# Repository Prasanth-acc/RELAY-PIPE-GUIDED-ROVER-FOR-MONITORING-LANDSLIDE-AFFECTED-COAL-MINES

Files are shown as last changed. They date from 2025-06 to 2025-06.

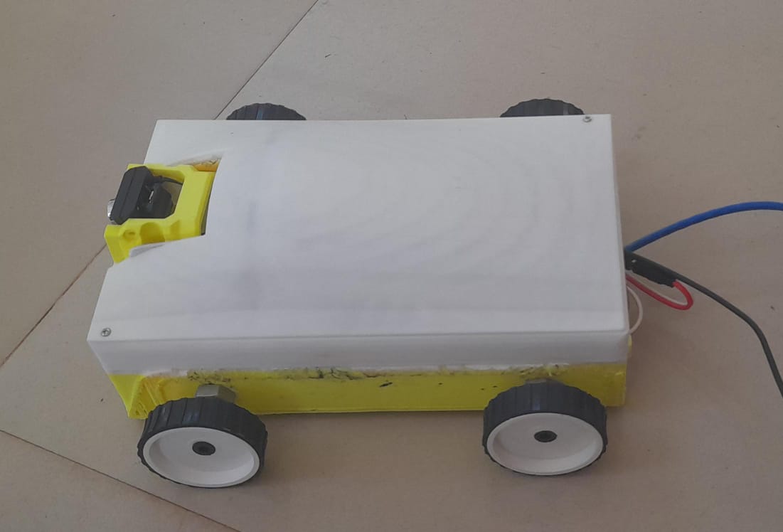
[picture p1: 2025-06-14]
Images/rover final.jpg

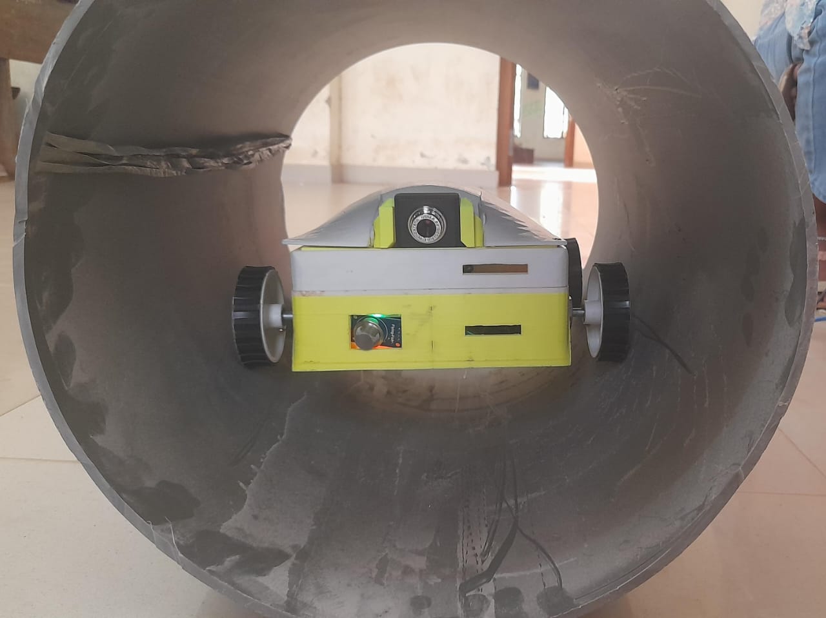
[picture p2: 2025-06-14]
Images/rover inside pipe.jpg

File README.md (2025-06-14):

# RELAY-PIPE-GUIDED-ROVER-FOR-MONITORING-LANDSLIDE-AFFECTED-COAL-MINES
This project develops a compact, remotely controlled rover designed for monitoring underground coal mines. Using custom CAD-designed parts, the rover navigates tight tunnels and gathers real-time data to assess mine safety. Communication with the base station is done via a wired RJ45 Ethernet connection to ensure reliable data transfer in challenging underground environments.

The rover is equipped with sensors and a camera system that allow operators to control its movement and view live feedback from the mine. This setup provides a safer way to monitor hazardous conditions and helps plan rescue operations by delivering crucial information without exposing humans to risk.
# ABSTRACT
In the wake of coal mine collapses, where workers often find themselves trapped and
 isolated, the urgency for rapid and effective rescue operations is paramount. This
 project aims to address such critical situations by designing and developing a state
of-the-art rover capable of navigating through a strategically drilled pipe to the far side
 of a collapsed mine. The primary objective is to equip rescue teams with real-time
 data and communication capabilities, significantly enhancing the efficiency and safety
 of underground rescue missions.
 
 The rover is engineered to traverse through a narrow pipe drilled through the soil,
 reaching the trapped zone with precision. It is equipped with high-resolution cameras
 capable of capturing detailed images even in low-light conditions, along with advanced
 environmental sensors that measure critical parameters such as gas levels, temperature,
 and humidity. Central to the rover's functionality is the BeagleY-AI board, which serves as the onboard processing unit.These sensors and cameras are vital for assessing the conditions within
 the collapsed mine and detecting potential hazards that could endanger the lives of both
 the trapped workers and the rescue team.
 
 Central to the rover’s functionality is its onboard processing unit, which integrates
 and analyses captured data in real-time. This processing capability ensures that
 only relevant and high-priority information is managed efficiently while transmitting
 everything directly to the base station via a wired connection with real-time, instan
taneous transmission. Unlike traditional wireless communication, which suffers from
 signal interference and delays in underground environments, this wired communication
 system guarantees uninterrupted and ultra-fast data transfer of video, sensor data, and
 audio.
 
 The base station is equipped with a dedicated Graphical User Interface (GUI)
 that enables rescue teams to view live footage, monitor sensor readings, and control
the rover remotely in real time. The instantaneous transmission allows operators
 to make swift and informed decisions. Moreover, the rover facilitates direct two
way communication with trapped workers, allowing rescue teams to provide real-time
 instructions and reassurance while receiving critical updates from the workers location.
 This feature is crucial in maintaining morale and gathering first-hand information about
 the situation.
 
 By integrating the BeagleY-AI board with environmental sensing, and a robust, real-time
 wired communication system, this project aims to offer a comprehensive solution
 for underground rescue operations. The developed rover will provide rescuers
 with invaluable insights, enabling them to make swift, informed decisions, thereby
 increasing the likelihood of a successful rescue. This innovative approach not only
 enhances the effectiveness of emergency response efforts in coal mine disasters but
 also sets a new standard for safety in hazardous underground environments.

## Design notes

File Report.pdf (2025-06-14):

# Contents

Abstract | i
Acknowledgement | iii
List of Figures | vii
1 Introduction | 1
2 Motivation | 2
3 Literature Review | 3
4 Methodology | 5

iv

5 Implementation | 12
6 Hardwares and Softwares | 17

v

7 Program | 22
8 | Result | 38
9 Scope for future applications | 41
10 Conclusion | 43
References | 45

vi

# List of Figures

4.1 2D design of rover | | 7
4.2 Model of lower chassis | | 8
4.3 Model of upper chassis | | 8
4.4 Model of rover | | 8
4.5 GUI | | 9
4.6 Simple program in Beagle Y AI board | | 10
5.1 Block diagram | | 12
5.2 Hardware circuit diagram | | 14
6.1 Beagle Y AI board | | 17
6.2 Arducam 1MX477 | | 18
6.3 MQ135-gas sensor | | 18
6.4 DHT11-temperature and humidity sensor | | 19
6.5 Slim Mini Audio Speaker (80 Ohm, 24x40mm) | | 19
6.6 InvenSense ICS43434-microphone | | 20
8.1 Final 3D model of rover | | 38
8.2 Hardware integration | | 39
8.3 GUI at base station | | 39
8.4 rover moving through pipe | | 40
8.5 output from beagle board | | 40

vii

# Chapter 1

# Introduction

The increasing frequency of mining accidents and natural disasters has necessitated

the development of innovative solutions for effective search and rescue operations. In

situations where traditional rescue methods may be hindered by debris or confined

spaces, robotic technologies offer a viable alternative to enhance safety and efficiency.

This project introduces an advanced rover specifically designed to navigate through

strategically drilled pipes, providing access to areas that are otherwise challenging for

human rescuers.

Equipped with high-resolution cameras and sophisticated environmental sensors,

the rover captures real-time images and monitors environmental conditions. Utilizing

the BeagleY-AI board for onboard processing, the rover employs advanced image

processing algorithms to enhance visibility in low-light and dusty environments, which

is critical for assessing the conditions of trapped individuals.

To facilitate effective communication, the rover features a two-way audio system,

allowing trapped individuals to interact directly with rescuers. This interaction not

only provides emotional support but also enables rescuers to gather vital information,

improving the overall effectiveness of the rescue effort.

This project aims to demonstrate the potential of robotics in enhancing the safety

and effectiveness of rescue operations. By integrating real-time video transmission,

environmental sensing, and communication technologies, the rover serves as a vital

resource in improving outcomes in emergency situations, ultimately contributing to

the successful recovery of trapped individuals.

1

# Chapter 2

# Motivation

The motivation behind this project arises from the significant safety challenges and

operational hazards associated with coal mining, particularly in the aftermath of

landslides. Landslides in mining areas can create unstable environments,obstruct

pathways, and release hazardous gases,making it dangerous and often impossible for

personnel to conduct direct inspections. Such conditions call for advanced solutions

that can mitigate risks while ensuring effective monitoring and data collection.

Traditional inspection methods are either labor-intensive or unsuitable for confined

spaces filled with toxic gases, low visibility, and unstable terrain. Robotic systems offer

a promising alternative by enabling remote, real-time assessment without endangering

human lives. By deploying a specialized rover that integrates navigation aids, multi-

sensor capabilities, and reliable communication systems, this project aims to enhance

post-landslide safety protocols.

Moreover, the rising demand for more autonomous and efficient mining solutions

emphasizes the need for innovation in this field. The rover’s ability to navigate through

strategically drilled pipes and perform detailed environmental monitoring could lead to

broader applications in mining, rescue operations, and even other high-risk industries.

The project is, therefore, driven by a commitment to improving mine safety, increasing

efficiency, and minimizing the risks associated with underground inspections.

2

# Chapter 3

# Literature Review

The Role of Robotics in Hazardous Environments[1,3]: Robotics has gained

significant attention for applications in hazardous and inaccessible areas, where human

presence may be unsafe or impractical. Many researchers highlights that autonomous

and semi-autonomous robotic systems have been successfully deployed in high-risk

areas, such as nuclear plants, deep-sea exploration, and disaster-stricken zones. These

robots can perform inspections, monitor environmental conditions, and relay critical

information back to human operators. This capability is particularly important in post-

landslide scenarios within coal mines, where unstable structures and toxic gases create

unsafe conditions for humans. Robotic inspection systems provide a viable solution by

reducing risk while allowing continuous data collection to assess stability and safety.

Guidance and Navigation in Confined Space [4]: Navigation in confined

and debris-filled spaces, such as those found in coal mines, requires specialized

techniques to ensure stability and accuracy, which emphasize the importance of guided

systems—rails, tethers, or relay pipes—that allow robots to move safely through

narrow and hazardous areas. Relay pipes, specifically, provide a path that helps

maintain the stability and orientation of the rover, even in environments with poor

visibility or challenging terrain. This technology has been applied in urban search-and-

rescue missions, showing success in guiding robotic platforms through narrow spaces

while preventing deviations that could lead to navigation errors or loss of control.

Environmental Monitoring and Gas Detection in Mining Applications [2,7,8]:

One of the most critical safety concerns in coal mines is the presence of toxic or explo-

3

sive gases, including methane and carbon monoxide. The mining industry frequently

encounters these gases, especially following landslides, as they can accumulate in

newly created cavities or pockets.Ga s sensors, such as the MQ-series (e.g., MQ-7

for carbon monoxide and MQ-4 for methane), have become standard for real-time

monitoring in underground environments, which shows that these sensors are effective

in identifying dangerous gas concentrations and can be integrated into mobile robotic

systems for continuous monitoring. Additionally, infrared (IR) gas sensors have been

used for detecting methane due to their accuracy and sensitivity. Integrating such

sensors into an inspection rover provides a reliable means of assessing air quality and

warning operators of dangerous levels of toxic gases.

Ethernet Communication in Robotics [9,14,10]: Ethernet technology has be-

come a cornerstone in industrial robotics, providing a standardized, high-bandwidth

medium for data exchange between system components. The adoption of Ethernet-

based protocols, enables seamless integration with existing network infrastructures,

enhancing interoperability and simplifying system architecture. This integration

allows for centralized control and data collection, improving efficiency and reducing

latency in robotic operations.

4

# Chapter 4

# Methodology

## 4.1 System Design and Requirements Analysis:

The development of the rover began with an in-depth analysis of the operational

requirements needed for effective deployment in confined underground environments.

The primary objective was to create a compact yet efficient system capable of

maneuvering through relay pipes drilled in collapsed coal mines. Key considerations

included designing a structure that ensures seamless mobility, integrating a robust

wired communication system for uninterrupted data transmission, and incorporating

environmental sensors for real-time monitoring of hazardous gases, temperature,

and humidity levels. The rover was also required to support real time video

transmission and bidirectional audio communication, enabling real-time interaction

between trapped workers and rescue operators.To enhance usability, a graphical user

interface (GUI) was developed at the base station, providing a centralized platform

for monitoring and controlling the rover. This interface displays the real-time video

feed, environmental sensor readings, and system diagnostics, ensuring operators have

all necessary data at a glance. Additionally, the GUI includes interactive controls,

allowing operators to navigate the rover remotely and make crucial decisions based

on live feedback. These requirements guided the selection of appropriate hardware

components, communication technologies, and software development strategies to

ensure the rover’s reliability in rescue operations.

| 5

## 4.2 Hardware Selection and Integration:

### 4.2.1 Locomotion and Chassis Design:

The chassis design focused on creating a lightweight yet structurally stable frame that

could navigate through confined spaces while withstanding underground conditions.

The rover was designed to move within a relay pipe, requiring a compact and durable

body that would prevent obstruction while maintaining balance. High-torque DC

motors were selected to drive the wheels, ensuring sufficient force for movement while

operating efficiently within the power constraints .

### 4.2.2 Power Supply and Distribution:

The rover is powered by a battery-based power supply, ensuring mobility without

dependence on external power sources. A lithium-polymer (LiPo) battery was selected

for its high energy density, lightweight characteristics, and ability to supply a stable

voltage output. A power management circuit was designed to regulate voltage levels,

preventing over voltage or under voltage conditions that could impact the performance

of motors and sensors. The distribution system was optimized to efficiently supply

power to all components, ensuring prolonged operational capability while maintaining

safety measures such as short-circuit protection and thermal management.

4.2.3 Sensor and Camera Integration;

To enhance situational awareness in the underground environment, the rover was

equipped with environmental monitoring sensors and a high-resolution camera system.

Gas sensors were integrated to detect hazardous gases.Additionally,temperature and

humidity sensors were added to provide real-time environmental data to rescue

operators. A high-resolution camera was mounted on the rover to capture live video

footage, which was transmitted to the base station.

6

### 4.2.4 Wired Communication Implementation:

A critical aspect of the rover’s design was the implementation of wired communication

technology to enable real-time data transmission.This system facilitated real-time con-

trol of the rover, bidirectional audio communication, and live video streaming. Control

signals from the base station were transmitted through the wired network, allowing

precise maneuverability and real-time response from the rover. The wired approach

eliminated concerns regarding wireless signal interference or loss of connectivity in

underground environments.

## 4.3 2D Design and Initial Conceptualization:

Following the component selection, a hand-drawn 2D design was created to visualize

the layout and arrangement of the components within the available space. The

hand-drawn design(Figure 4.1) provided an understanding of the positioning of each

component, ensuring efficient space usage and proper weight distribution for balanced

navigation. This initial conceptualization allowed for quick revisions and adjustments,

ensuring flexibility in the design process and ensured that all components would fit

within the confined space of the pipe, with an emphasis on stability to minimize tipping

risks.

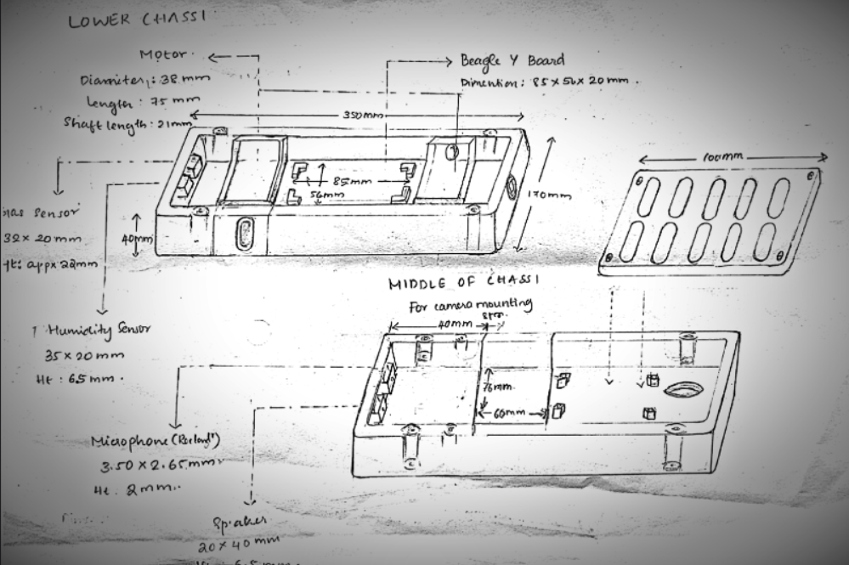
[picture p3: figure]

Figure 4.1: 2D design of rover

7

## 4.4 3D Modeling and Component Design:

After the 2D design, the rover was transitioned into a 3D model using CAD software,

SolidWorks.The 3D modeling phase provided a more detailed visualization of the

rover’s components in three dimensions, ensuring their fit and arrangement as shown

in Figure 4.2 ,Figure 4.3 and Figure 4.4. This step helped to identify potential issues

such as component overlap or misalignment. Adjustments were made to optimize

component sizes and positions to ensure effective navigation within the pipe while

maintaining the rover’s structural integrity and balance. The 3D model allowed for

accurate representation of the rover’s physical design, aiding in the evaluation of space

utilization and structural efficiency.

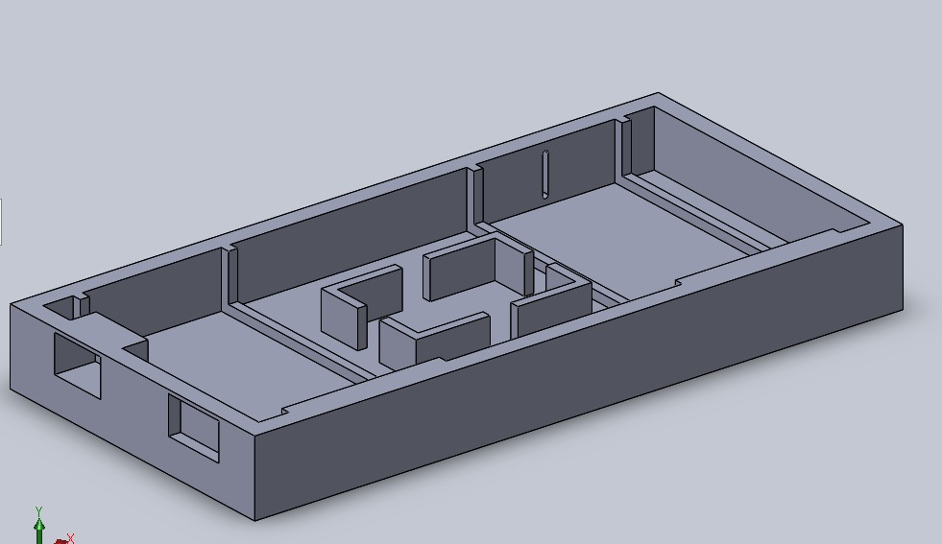
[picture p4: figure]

Figure 4.2: Model of lower chassis

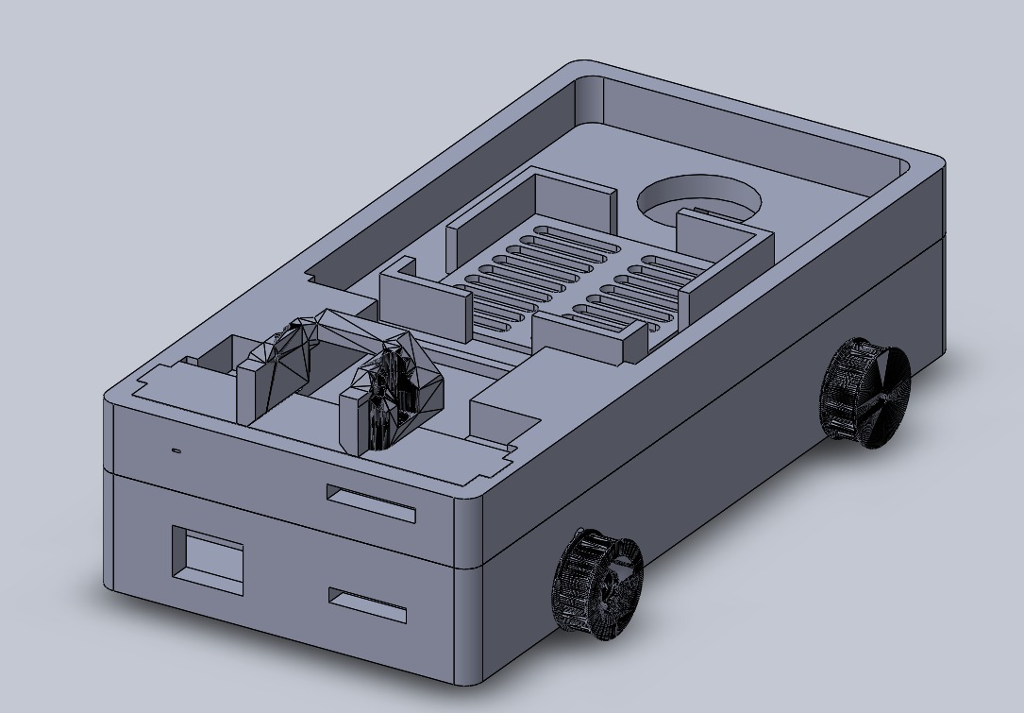
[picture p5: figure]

Figure 4.3: Model of upper chassis

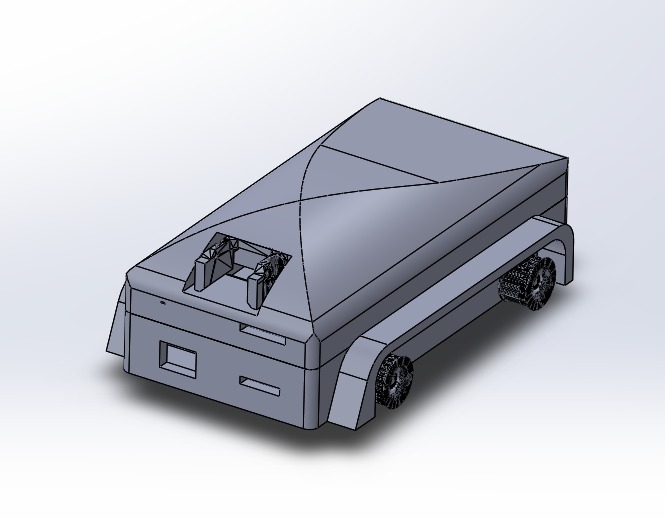
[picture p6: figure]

Figure 4.4: Model of rover

8

## 4.5 Software Development

### 4.5.1 Programming and Implementation:

The software architecture was developed to handle real-time video processing, sensor

data acquisition, and remote control functionalities. Python is used to program

the system, with multi-threading techniques employed to manage simultaneous data

transmission, motor control, and environmental monitoring. The rover’s software was

designed to interface with the base station, where a Graphical User Interface (GUI)

was developed to display live video feeds, sensor readings, and control parameters.

### 4.5.2 Graphical User Interface (GUI) at the Base Station:

A dedicated Graphical User Interface (GUI) was developed at the base station to

facilitate seamless interaction with the rover. The GUI serves as the central control

hub where all data from the rover, including live video feeds, environmental sensor

readings, and system status, are displayed in real-time. The interface allows rescue

operators to monitor underground conditions, analyze images processed by the rover,

and adjust control parameters as needed. Additionally, the GUI (Figure 4.5) provides

interactive controls for operating the rover, such as adjusting its movement and sensor

data.

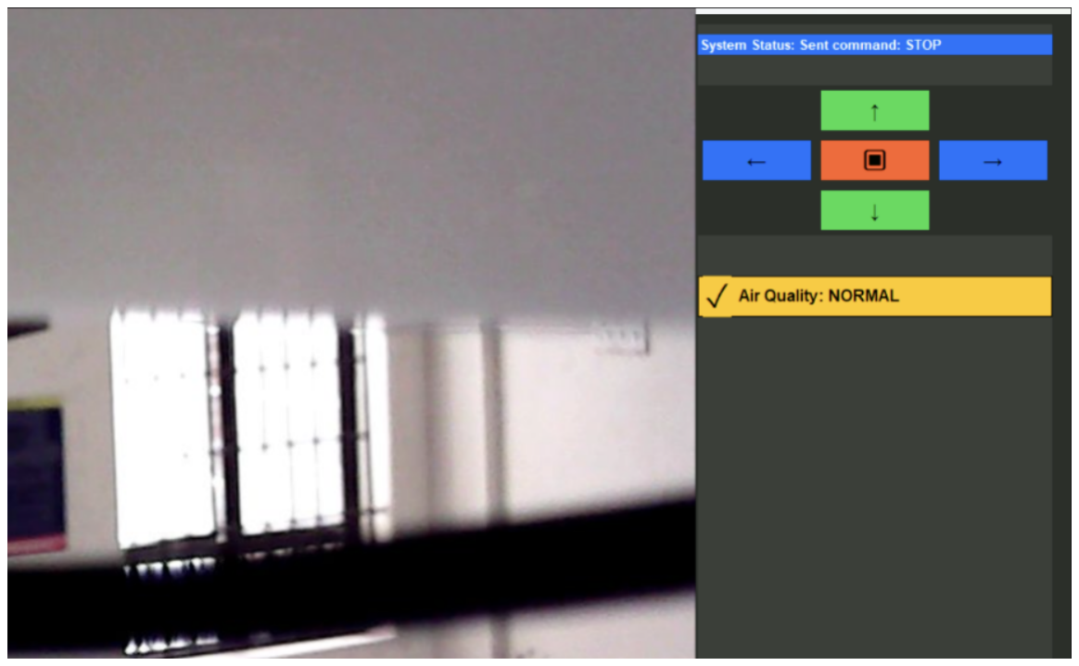
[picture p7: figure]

Figure 4.5: GUI

9

## 4.6 Hardware Testing:

Before full-scale deployment, individual hardware components were tested to ensure

their functionality. The motors, sensors, and communication modules were evaluated

under controlled conditions to verify their responsiveness and reliability. The Beagle

Y AI board was used to execute simple test programs that assessed sensor data

acquisition and motor operation. These preliminary tests confirmed that the rover could

process environmental inputs and execute movement commands accurately. The wired

communication system was tested separately to measure latency,and overall stability in

data transmission. Control signals, bidirectional audio communication, and real-time

video streaming were evaluated under simulated underground conditions. The results

indicated that the system could handle continuous data flow without delays, ensuring

effective remote operation.

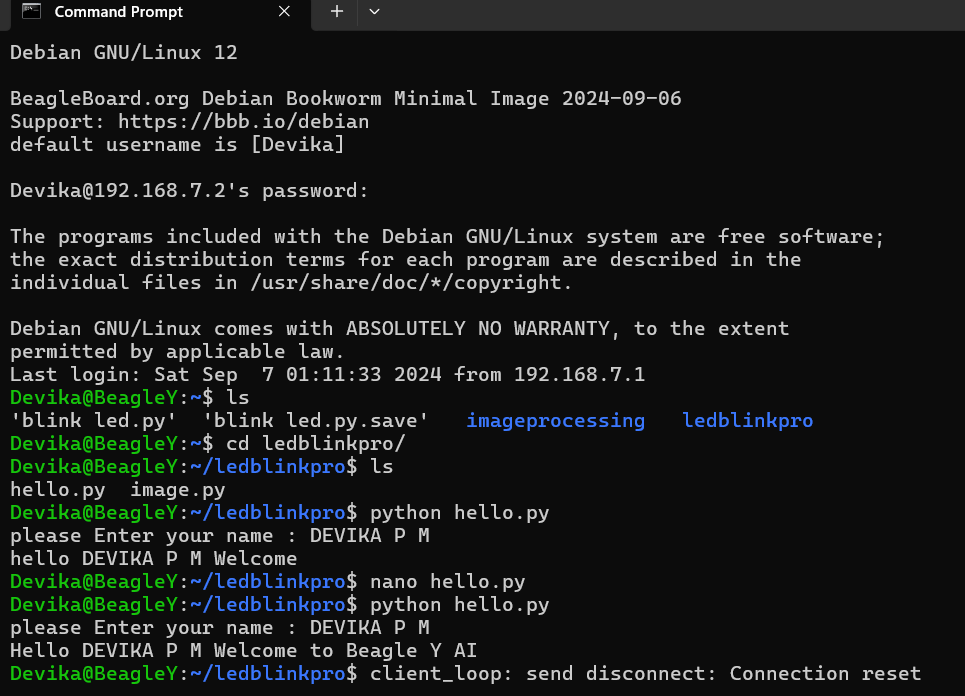
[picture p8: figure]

Figure 4.6: Simple program in Beagle Y AI board

## 4.7 Testing and Performance Evaluation

### 4.7.1 Environmental Sensor Validation:

The accuracy of the environmental sensors was tested in a controlled setup by exposing

them to varying conditions. Gas sensors were calibrated to detect different gases, under

different environmental conditions to ensure precise readings.

10

### 4.7.2 Rover Navigation Testing:

A simulated test environment was created to evaluate the rover’s movement through

a relay pipe. The rover was tested for stability, maneuverability, and response

to control signals. Adjustments were made to improve its movement and ensure

efficient navigation within confined spaces.The rover’s response to control signals was

tested to measure real-time communication effectiveness, ensuring minimal latency in

command execution.

### 4.7.3 Performance Analysis and Optimization

To ensure the rover’s reliability and efficiency, a series of performance tests were

conducted, focusing on communication latency, power efficiency, structural durability,

and environmental adaptability. The rover’s response time to control signals was

analyzed to minimize latency, with software optimizations implemented for real-

time communication. Its maneuverability was tested in confined spaces, leading

to adjustments in motor control algorithms for smoother turns and better path

optimization.

11

# Chapter 5

# Implementation

## 5.1 System Architecture(Conceptual Design)

The block diagram(Figure 5.1) represents the working architecture of the rover system,

which is designed to navigate and communicate through a wired connection

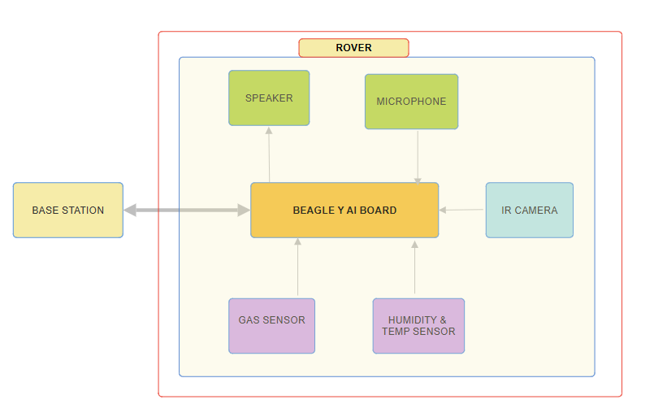
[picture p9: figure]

Figure 5.1: Block diagram

### 5.1.1 BeagleY-AI Board (Central Processing Unit)

The BeagleY-AI board is responsible for processing data, and controlling various

hardware components. It receives input from sensors and the microphone, processes

the data, and sends output commands to the motors, speaker, and base station.The

board also facilitates real-time wired communication with the base station.

12

### 5.1.2 Environmental sensors

Gas Sensor Detects air quality and sends data to the BeagleY-AI board.Humidity

and Temperature Sensor, Measures environmental conditions and provides necessary

information for analysis.

### 5.1.3 Microphone and Speaker

Microphone Captures real-time audio from the rover’s surroundings and sends it to

the BeagleY-AI board. Speaker Plays back audio signals received from the base

station or generated by the system. These components enable bi-directional voice

communication.

### 5.1.4 IR Camera

The IR Camera captures real-time video of the rover’s surroundings.The video feed

is processed by the BeagleY-AI board and transmitted to the base station via a wired

connection.

### 5.1.5 Motor Driver and Motors

The BeagleY-AI board controls the motors via the motor driver module.The motor

driver converts the control signals into high-power signals that can drive the motors

(M1 and M2).This enables the rover to move forward, backward, left, and right based

on commands from the base station or programmed logic.

### 5.1.6 Wired Communication with Base Station

The BeagleY-AI board sends sensor data, video feed, and audio to the base station.It

also receives control commands from the base station, such as motor movement

instructions and audio playback.This ensures real-time bi-directional communication

between the rover and rescue operators.

13

## 5.2 Hardware Wiring and Circuit Connections

The Figure 5.2, provides a detailed wiring layout of how the BeagleY-AI board

connects to various hardware components in the rover system.

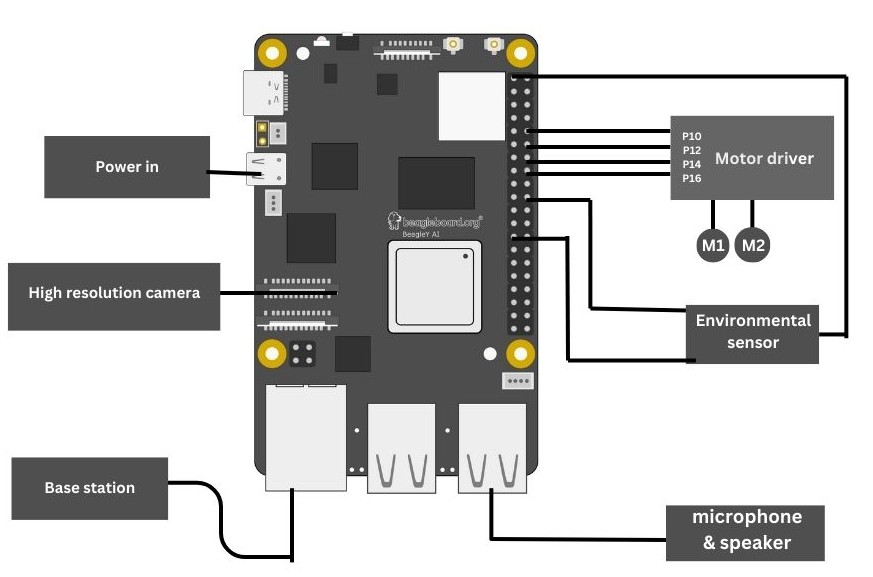
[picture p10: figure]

Figure 5.2: Hardware circuit diagram

### 5.2.1 Power Input

The BeagleY-AI board is powered through a USB or external power supply.This

ensures that all components, including the sensors, motors, and communication

modules, receive the necessary power.

### 5.2.2 Base Station Connection

The wired connection between the BeagleY-AI board and the base station allows for

real-time data transmission.This includes Bidirectional audio transmission,video and

sensor data transmission from rover to base station and control signal transmission

from base station to rover

14

### 5.2.3 Motor Driver and Motors (M1 , M2)

The motor driver is connected to the BeagleY-AI board via GPIO pins (P10, P12, P14,

and P16). The BeagleY-AI board sends control signals to the motor driver.The motor

driver then amplifies the signals and drives two motors (M1 and M2). This allows the

rover to move forward, backward, left, or right based on base station commands.

## 5.3 Hardware Assembly and Integration:

The physical assembly of the rover was carried out by integrating the selected

hardware components into the designed chassis. The Beagle Y AI board was securely

mounted within the rover’s structure, ensuring proper connectivity with other essential

components. The high-resolution infrared camera was positioned strategically to

capture optimal video feeds for real-time processing.

The environmental sensors, including temperature, humidity, and gas sensors,

were installed at appropriate locations to ensure accurate monitoring of underground

conditions. Special care was taken to organize the wiring layout efficiently to minimize

interference and potential damage during movement.

The rover’s mobility system, consisting of motors and chains, was tested for

smooth operation. The chassis underwent multiple refinements to ensure optimal

balance and stability while navigating confined spaces, such as a relay pipe in a

collapsed mine.

## 5.4 Software Deployment and System Integration:

The software developed in the earlier phase was implemented on the Beagle Y AI

board, ensuring real-time control and data management. Multi-threading techniques

were used to handle concurrent tasks such as video streaming, sensor data acquisition,

and motor control without latency issues. The processed data, including live video

feeds and environmental sensor readings, was transmitted to the base station through

the wired communication system.

15

## 5.5 Communication System Design

The rover is equipped with a wired communication system to enable uninterrupted

data transmission. This system established a direct connection between the rover and

the base station, ensuring high-speed, interference-free data transfer. It facilitated real-

time transmission of video, sensor data, and control signals for precise operation.

## 5.6 Testing and Refinements

After hardware and software integration, the system was tested in a controlled

environment. The rover’s movement and response to control signals were evaluated to

ensure smooth navigation through confined spaces. Sensor readings were verified, and

necessary adjustments were made to improve performance. The wired communication

system was also tested for stability, confirming real-time bidirectional data exchange.

16

# Chapter 6

# Hardwares and Softwares

## 6.1 Hardware Components

### 6.1.1 Beagle Y AI Board

The Beagle Y AI Board is a powerful single-board computer optimized for AI and

machine learning tasks, featuring advanced processing capabilities and a variety of

I/O interfaces, shown in Figure 6.1 . Equipped with an AI-optimized processing

unit, it supports real-time data processing, multimedia functions, and edge computing,

making it ideal for applications in robotics, automation, and IoT. The board’s high-

speed communication capabilities enhance its versatility, allowing it to handle complex

tasks like data analysis, sensor integration, and multimedia processing efficiently.

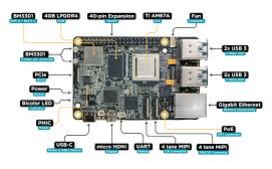
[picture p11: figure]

Figure 6.1: Beagle Y AI board

17

### 6.1.2 Arducam 1MX477

The Arducam 1MX477 is a high-quality camera module based on the Sony IMX477

image sensor, known for its exceptional low-light performance, high resolution, and

adaptability to a range of imaging tasks. Designed primarily for applications needing

detailed visuals in challenging conditions, this camera is widely used in robotics,

drones, surveillance, and industrial inspections as shown in Figure 6.3. Its capabilities

make it ideal for environments where clarity and precision are paramount, such as the

interior of a mine.

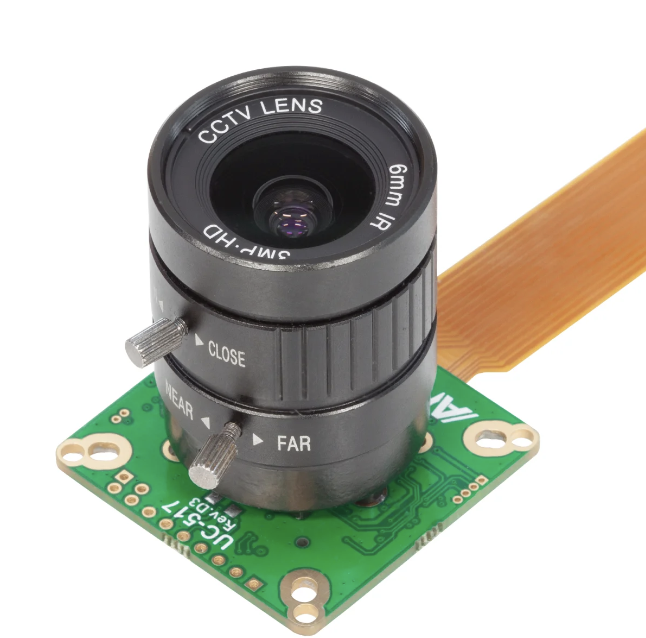
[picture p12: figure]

Figure 6.2: Arducam 1MX477

### 6.1.3 MQ135 Gas Sensor

The MQ135 Gas Sensor is a sensor module commonly used for air quality monitoring,

capable of detecting a range of hazardous gases(Figue 6.3). It is specifically designed

to detect gases such as ammonia (NH3), sulfur, benzene, smoke, Carbon dioxide, and

other potentially toxic gases.

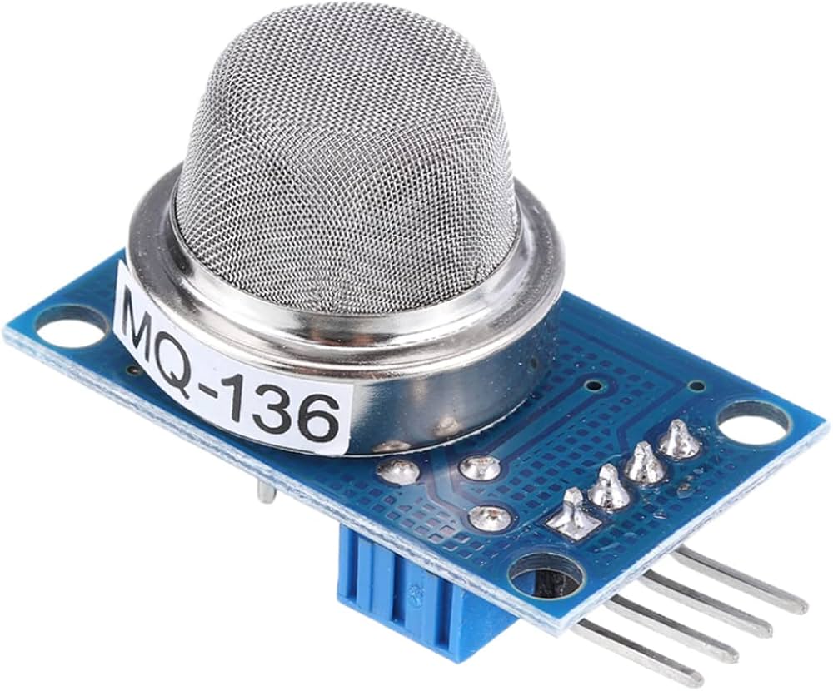
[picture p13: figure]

Figure 6.3: MQ135-gas sensor

18

### 6.1.4 DHT11 Temperature and Humidity Sensor

The DHT11 is a low-cost, digital sensor used to measure temperature and hu-

midity(Figure 6.4). It operates on a supply voltage between 3.5V and 5.5V and

communicates with a microcontroller through a single-wire digital signal. The sensor

contains a humidity sensing component and a thermistor, converting analog data into

a digital signal, which is then processed by the microcontroller.

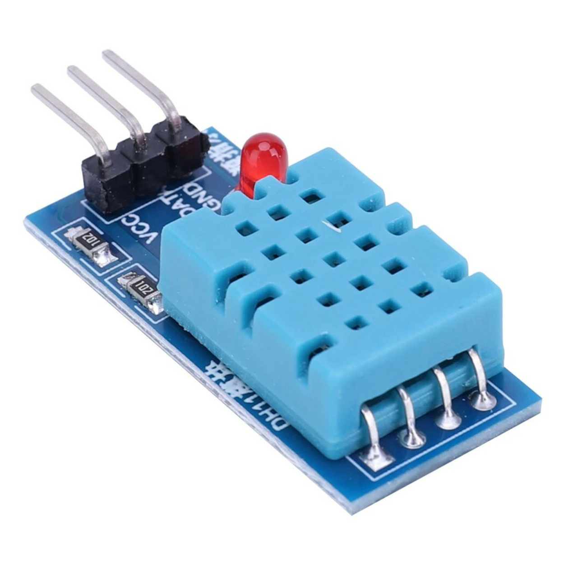
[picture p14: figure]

Figure 6.4: DHT11-temperature and humidity sensor

### 6.1.5 Slim Mini Audio Speaker (80 Ohm, 24x40mm)

The Slim Mini Audio Speaker (80 Ohm, 24x40mm)is a compact speaker designed for

space-constrained electronic projects (Figure 6.5). With an impedance of 80 ohms, it is

suitable for low-power devices and produces clear sound for basic audio applications,

such as voice prompts, alerts, and notifications.

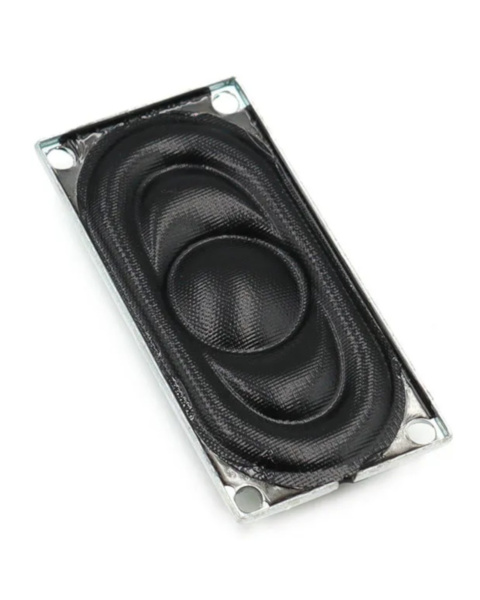
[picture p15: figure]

Figure 6.5: Slim Mini Audio Speaker (80 Ohm, 24x40mm)

19

### 6.1.6 InvenSense ICS43434

The InvenSense ICS43434 is a high-performance digital MEMS microphone designed

for use in various audio applications, including consumer electronics, smartphones,

smart speakers, and voice-controlled devices as shown in Figure 6.6. It features

a digital I2S output interface, which simplifies the integration of the microphone

with digital processing systems, such as microcontrollers or digital signal processors

(DSPs).

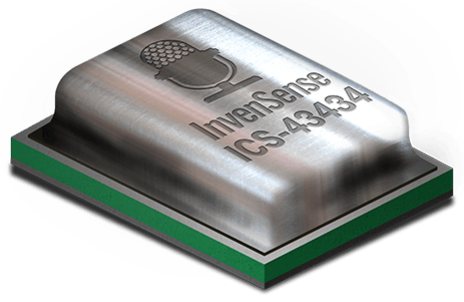
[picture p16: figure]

Figure 6.6: InvenSense ICS43434-microphone

## 6.2 Software Components

### 6.2.1 Visual Studio Code

VS Code is a popular and lightweight code editor that supports a wide range of

programming languages and offers numerous extensions, making it an ideal tool for

embedded systems development. It provides features such as syntax highlighting,

debugging, version control integration, and a customizable environment, helping

developers streamline the coding process. With its support for various extensions and

its ability to handle large projects, VS Code is widely used in the development of both

simple and complex software systems.

### 6.2.2 ROS Construct

ROS Construct is a framework designed to simplify the use of the Robot Operating

System (ROS) by providing tools for simulation, testing, and integration of robotic sys-

tems. It offers a user-friendly interface for configuring and managing ROS packages,

hardware interfaces, and simulation environments, making it easier for developers to

20 design, test, and deploy robots. ROS Construct enhances the development process

by allowing for easy simulation and debugging, particularly in the context of robotic

applications and autonomous systems.

### 6.2.3 SolidWorks

SolidWorks is a leading 3D CAD (Computer-Aided Design) software used for

designing, modeling, and simulating mechanical parts and assemblies. It is widely

used in engineering to create detailed 3D models that can be tested and visualized

before actual manufacturing. SolidWorks offers a range of tools for designing complex

mechanical systems, performing simulations (such as stress analysis), and generating

technical drawings. Its intuitive interface and powerful design capabilities make it a

key tool for prototyping and product development across various industries.

21

# Chapter 7

# Program

## 7.1 Code for Base station

# final

import tkinter as tk

from tkinter import ttk

from PIL import Image , ImageTk

import cv2

import numpy as np

import socket

import struct

import threading

import queue

import pyaudio

# Configuration

HOST = ’192.168.1.10’ # BeagleBone AI IP

VIDEO_PORT = 5000

AUDIO_PORT = 5001

SENSOR_PORT = 5002

MOTOR_AUDIO_PORT = 5003

# UI Configuration

22

COLORS = {

"dark_bg": "#2a2a2a",

"light_bg": "#3a3a3a",

"accent": "#2196f3",

"success": "#4caf50",

"danger": "#f44336",

"warning": "#ff9800",

"text": "#ffffff"

}

class RoverClient :

def _init_(self , root):

self.root = root

self.running = True

# Video and audio queues

self. video_queue = queue.Queue(maxsize =2)

self. audio_queue = queue.Queue(maxsize =10)

# Network connections

self. motor_audio_socket = None

# Initialize GUI

self. setup_gui ()

# Audio setup

self.audio = pyaudio.PyAudio ()

self. audio_stream = self.audio.open(

format=pyaudio.paInt16 ,

channels =2,

rate =44100 ,

output=True

)

self. input_stream = self.audio.open(

23

format=pyaudio.paInt16 ,

channels =2,

rate =44100 ,

input=True ,

frames_per_buffer =1024

)

# Start network connections

self. connect_services ()

# Start processing threads

threading .Thread(target=self.receive_video , daemon=

True).start ()

threading .Thread(target=self.receive_audio , daemon=

True).start ()

threading .Thread(target=self.receive_sensor , daemon=

True).start ()

threading .Thread(target=self.play_audio , daemon=True).

start ()

threading .Thread(target=self.send_audio , daemon=True).

start ()

# Start UI updates

self. update_video ()

def setup_gui (self):

self.root.title("Rover Control Center")

self.root.geometry ("1280x720")

self.root. configure (bg=COLORS["dark_bg"])

# Main container

main_frame = ttk.Frame(self.root)

main_frame .pack(expand=True , fill=tk.BOTH , padx =10,

pady =10)

24

# Video panel

video_frame = ttk.Frame( main_frame )

video_frame .pack(side=tk.LEFT , expand=True , fill=tk.

BOTH)

self. video_label = ttk.Label(video_frame , background ="

black")

self. video_label .pack(expand=True , fill=tk.BOTH)

# Control panel

control_frame = ttk.Frame(main_frame , width =300 , style

="Control.TFrame")

control_frame .pack(side=tk.RIGHT , fill=tk.Y, padx =10)

# Status display

self. status_label = ttk.Label(

control_frame ,

text="System Status: Connecting...",

style="Status.TLabel"

)

self. status_label .pack(pady =10, fill=tk.X)

# Motor controls

self. create_motor_controls ( control_frame )

# Sensor display

self. sensor_frame = ttk.Frame(control_frame , style="

Sensor.TFrame")

self. sensor_frame .pack(pady =20, fill=tk.X)

self. sensor_icon = ttk.Label(

self.sensor_frame ,

text=" ",

25

font =("Arial", 24) ,

style="Sensor.TLabel"

)

self. sensor_icon .pack(side=tk.LEFT , padx =5)

self. sensor_label = ttk.Label(

self.sensor_frame ,

text="Air Quality: Initializing...",

style="Sensor.TLabel"

)

self. sensor_label .pack(side=tk.LEFT)

# Configure styles

self. configure_styles ()

def configure_styles (self):

style = ttk.Style ()

style. theme_create ("custom", settings ={

"TFrame": {"configure": {"background": COLORS["

dark_bg"]}},

"TLabel": {"configure": {

"background": COLORS["dark_bg"],

"foreground": COLORS["text"],

"font": ("Arial", 10)

}},

"Control.TFrame": {"configure": {"background":

COLORS["light_bg"]}},

"Sensor.TFrame": {"configure": {

"background": COLORS["warning"],

"borderwidth": 1,

"relief": "solid"

}},

"Sensor.TLabel": {"configure": {

"background": COLORS["warning"],

26

"foreground": "#000000",

"font": ("Arial", 12, "bold")

}},

"Status.TLabel": {"configure": {

"background": COLORS["accent"],

"foreground": COLORS["text"],

"font": ("Arial", 10, "bold")

}}

})

style. theme_use ("custom")

def create_motor_controls (self , parent):

control_frame = ttk.Frame(parent)

control_frame .pack(pady =20)

btn_style = {

"font": ("Arial", 14, "bold"),

"width": 8,

"relief": "flat"

}

# Forward button

self. btn_forward = tk.Button(

control_frame ,

text=" ",

bg=COLORS["success"],

command=lambda: self. send_motor_command ("forward")

,

** btn_style

)

self. btn_forward .grid(row=0, column =1, padx =5, pady =5)

# Left button

self.btn_left = tk.Button(

27

control_frame ,

text=" ",

bg=COLORS["accent"],

command=lambda: self. send_motor_command ("left"),

** btn_style

)

self.btn_left .grid(row=1, column =0, padx =5, pady =5)

# Stop button

self.btn_stop = tk.Button(

control_frame ,

text=" ",

bg=COLORS["danger"],

command=lambda: self. send_motor_command ("stop"),

** btn_style

)

self.btn_stop .grid(row=1, column =1, padx =5, pady =5)

# Right button

self. btn_right = tk.Button(

control_frame ,

text=" ",

bg=COLORS["accent"],

command=lambda: self. send_motor_command ("right"),

** btn_style

)

self. btn_right .grid(row=1, column =2, padx =5, pady =5)

# Reverse button

self. btn_reverse = tk.Button(

control_frame ,

text=" ",

bg=COLORS["success"],

28 command=lambda: self. send_motor_command ("reverse")

,

** btn_style

)

self. btn_reverse .grid(row=2, column =1, padx =5, pady =5)

def connect_services (self):

try:

self. motor_audio_socket = socket.socket(socket.

AF_INET , socket. SOCK_STREAM )

self. motor_audio_socket .connect ((HOST ,

MOTOR_AUDIO_PORT ))

self. update_status ("Connected to motor/audio

controller")

except Exception as e:

self. update_status (f"Connection failed: {str(e)}")

def send_motor_command (self , command):

try:

if self. motor_audio_socket :

# Send motor command with header

header = struct.pack(’!BH’, 0,len(command)) #

0 for motor command

self. motor_audio_socket .sendall(header +

command.encode ())

self. update_status (f"Sent command: {command.

upper()}")

except Exception as e:

self. update_status (f"Command failed: {str(e)}")

def send_audio (self):

while self.running:

try:

audio_data = self. input_stream .read (1024)

29 if self. motor_audio_socket :

# Send audio with header (1 for audio data

) and size

header = struct.pack(’!BI’, 1, len(

audio_data ))

self. motor_audio_socket .sendall(header +

audio_data )

except Exception as e:

print(f"Audio send error: {str(e)}")

break

def receive_video (self):

sock = socket.socket(socket.AF_INET , socket.

SOCK_STREAM )

try:

sock.connect ((HOST , VIDEO_PORT ))

while self.running:

size_data = sock.recv (4)

if len( size_data ) != 4:

break

size = struct.unpack(’!I’, size_data )[0]

data = b’’

while len(data) < size:

data += sock.recv(size - len(data))

self. video_queue .put(data)

finally:

sock.close ()

def receive_audio (self):

sock = socket.socket(socket.AF_INET , socket.

SOCK_STREAM )

try:

sock.connect ((HOST , AUDIO_PORT ))

while self.running:

30

size_data = sock.recv (4)

if len( size_data ) != 4:

break

size = struct.unpack(’!I’, size_data )[0]

data = b’’

while len(data) < size:

data += sock.recv(size - len(data))

#print(data)

self. audio_queue .put(data)

finally:

sock.close ()

def receive_sensor (self):

sock = socket.socket(socket.AF_INET , socket.

SOCK_STREAM )

try:

sock.connect ((HOST , SENSOR_PORT ))

while self.running:

size_data = sock.recv (4)

if len( size_data ) != 4:

break

size = struct.unpack(’!I’, size_data )[0]

data = b’’

while len(data) < size:

data += sock.recv(size - len(data))

#print(data)

self. process_sensor_data (data)

finally:

sock.close ()

def play_audio (self):

while self.running:

try:

data = self. audio_queue .get(timeout =0.1)

31 self. audio_stream .write(data)

except queue.Empty:

pass

def update_video (self):

try:

data = self. video_queue . get_nowait ()

frame = cv2.imdecode(np. frombuffer (data , np.uint8)

, cv2. IMREAD_COLOR )

if frame is not None:

frame = cv2.cvtColor(frame , cv2. COLOR_BGR2RGB )

img = Image. fromarray (frame)

imgtk = ImageTk. PhotoImage (image=img)

self. video_label .config(image=imgtk)

self. video_label .image = imgtk

except queue.Empty:

pass

self.root.after (10, self. update_video )

def process_sensor_data (self , data):

try:

value = data.decode ()

#print(value)

if value == ’0’:

self. sensor_label .config(text="Air Quality:

NORMAL")

self. sensor_frame .config(style="Sensor.TFrame"

)

self. sensor_icon .config(text=" ", foreground

="#000000")

else:

self. sensor_label .config(text="Air Quality:

TOXIC!")

32 self. sensor_frame .config(style="Danger.TFrame"

)

self. sensor_icon .config(text=" ", foreground

="#ff0000")

except:

self. sensor_label .config(text="Sensor Error")

self. sensor_frame .config(style="Danger.TFrame")

def update_status (self , message):

self. status_label .config(text=f"System Status: {

message}")

def on_close(self):

self.running = False

try:

self. motor_socket .close ()

self. audio_stream . stop_stream ()

self. audio_stream .close ()

self.audio. terminate ()

except:

pass

self.root.destroy ()

if _name_ == ’_main_’:

root = tk.Tk()

client = RoverClient (root)

root.protocol ("WM_DELETE_WINDOW", client.on_close)

root.mainloop ()

## 7.2 Code for Rover

import socket

import threading

33

import queue

import cv2

import pyaudio

import Adafruit_BBIO .GPIO as GPIO

import Adafruit_BBIO .ADC as ADC

import time

# Motor Configuration

LEFT_MOTOR_IN1 = "P8_10"

LEFT_MOTOR_IN2 = "P8_12"

RIGHT_MOTOR_IN3 = "P8_14"

RIGHT_MOTOR_IN4 = "P8_16"

GPIO.setup(LEFT_MOTOR_IN1 , GPIO.OUT)

GPIO.setup(LEFT_MOTOR_IN2 , GPIO.OUT)

GPIO.setup(RIGHT_MOTOR_IN3 , GPIO.OUT)

GPIO.setup(RIGHT_MOTOR_IN4 , GPIO.OUT)

def motor_control (cmd):

if cmd == ’forward’:

GPIO.output(LEFT_MOTOR_IN1 , GPIO.HIGH)

GPIO.output(LEFT_MOTOR_IN2 , GPIO.LOW)

GPIO.output(RIGHT_MOTOR_IN3 , GPIO.HIGH)

GPIO.output(RIGHT_MOTOR_IN4 , GPIO.LOW)

elif cmd == ’backward’:

GPIO.output(LEFT_MOTOR_IN1 , GPIO.LOW)

GPIO.output(LEFT_MOTOR_IN2 , GPIO.HIGH)

GPIO.output(RIGHT_MOTOR_IN3 , GPIO.LOW)

GPIO.output(RIGHT_MOTOR_IN4 , GPIO.HIGH)

elif cmd == ’left’:

GPIO.output(LEFT_MOTOR_IN1 , GPIO.LOW)

GPIO.output(LEFT_MOTOR_IN2 , GPIO.HIGH)

GPIO.output(RIGHT_MOTOR_IN3 , GPIO.HIGH)

GPIO.output(RIGHT_MOTOR_IN4 , GPIO.LOW)

34

elif cmd == ’right’:

GPIO.output(LEFT_MOTOR_IN1 , GPIO.HIGH)

GPIO.output(LEFT_MOTOR_IN2 , GPIO.LOW)

GPIO.output(RIGHT_MOTOR_IN3 , GPIO.LOW)

GPIO.output(RIGHT_MOTOR_IN4 , GPIO.HIGH)

elif cmd == ’stop’:

GPIO.output(LEFT_MOTOR_IN1 , GPIO.LOW)

GPIO.output(LEFT_MOTOR_IN2 , GPIO.LOW)

GPIO.output(RIGHT_MOTOR_IN3 , GPIO.LOW)

GPIO.output(RIGHT_MOTOR_IN4 , GPIO.LOW)

# Air Quality Sensor Setup

ADC.setup ()

AIR_QUALITY_PIN = "AIN0"

# Network Configuration

DATA_QUEUE = queue.Queue ()

LAPTOP_IP = "192.168.1.100" # Update this

DATA_PORT = 5000

# Initialize Data Socket

data_socket = socket.socket(socket.AF_INET , socket. SOCK_STREAM

)

data_socket .connect (( LAPTOP_IP , DATA_PORT ))

def data_sender ():

while True:

data_type , payload = DATA_QUEUE .get ()

header = data_type .ljust (5).encode ()

size = len(payload).to_bytes (4, ’big’)

data_socket .sendall(header + size + payload)

sender_thread = threading .Thread(target=data_sender , daemon=

True)

35

sender_thread .start ()

# Video Capture

def video_stream ():

cap = cv2. VideoCapture (0)

while True:

ret , frame = cap.read ()

if ret:

_, jpeg = cv2.imencode (’.jpg’, frame)

DATA_QUEUE .put ((’VIDEO’, jpeg.tobytes ()))

time.sleep (0.05)

video_thread = threading .Thread(target=video_stream , daemon=

True)

video_thread .start ()

# Audio Capture

audio = pyaudio.PyAudio ()

FORMAT = pyaudio.paInt16

CHANNELS = 1

RATE = 44100

CHUNK = 1024

def audio_stream ():

stream = audio.open(format=FORMAT , channels=CHANNELS ,

rate=RATE , input=True ,

frames_per_buffer =CHUNK)

while True:

DATA_QUEUE .put ((’AUDIO’, stream.read(CHUNK)))

stream. stop_stream ()

stream.close ()

audio_thread = threading .Thread(target=audio_stream , daemon=

True)

36

audio_thread .start ()

# Sensor Data

def sensor_data ():

while True:

value = ADC.read( AIR_QUALITY_PIN )

DATA_QUEUE .put ((’SENSOR’, str(value).encode ()))

time.sleep (1)

sensor_thread = threading .Thread(target=sensor_data , daemon=

True)

sensor_thread .start ()

def command_server ():

server = socket.socket(socket.AF_INET , socket. SOCK_STREAM )

server.bind ((’0.0.0.0’, 5001))

server.listen (1)

while True:

conn , _ = server.accept ()

while True:

cmd = conn.recv (1024).decode ().strip ()

if cmd:

motor_control (cmd)

conn.close ()

cmd_thread = threading .Thread(target=command_server , daemon=

True)

cmd_thread .start ()

while True:

time.sleep (1)

37

# Chapter 8

# Result

## 8.1 3D model of the rover

The Figure 8.1 presents the 3D model of the rover. This model provides a comprehen-

sive view of the rover’s structural design, highlighting components specifically tailored

for our project’s unique requirements.


Figure 8.1: Final 3D model of rover

## 8.2 Hardware integration in rover

The integration of hardware components, as depicted in Figure 8.2, consists of

several key elements that work together to ensure the efficient functioning of the

system. These components include a high-resolution camera for capturing a live

38 video feed, enabling real-time visual monitoring. A microphone is incorporated

for audio communication, allowing seamless interaction and transmission of voice

signals. Additionally, environmental sensors are deployed to collect crucial data

such as temperature, humidity, gas concentration, and other parameters essential for

situational awareness.

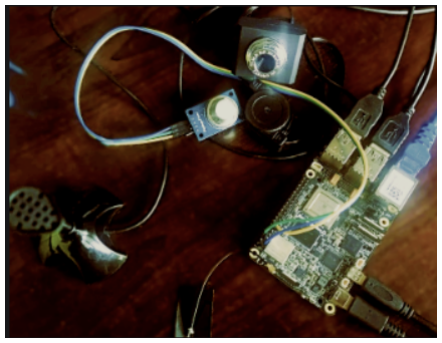
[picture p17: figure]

Figure 8.2: Hardware integration

## 8.3 Graphical User Interface at Base station

The GUI (Figure 8.3) at the base station provides an intuitive interface for monitoring

and controlling the rover. It displays the real-time video feed, sensor data, and system

status while offering on-screen controls for navigation and communication.

Figure 8.3: GUI at base station

39

## 8.4 Relay pipe guided rover

Figures 8.3 and 8.4 illustrate the final working model of the rover, showcasing the

integration of all hardware and software components into a fully functional system.

This model represents the culmination of extensive design, prototyping, and testing

phases, ensuring that all features operate seamlessly. The rover is equipped with

a robust chassis designed to navigate challenging terrains, including rocky surfaces,

narrow tunnels, and unstable environments such as collapsed coal mines.

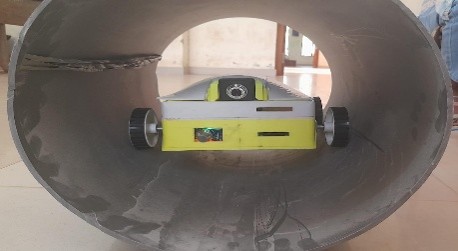
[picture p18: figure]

Figure 8.4: rover moving through pipe

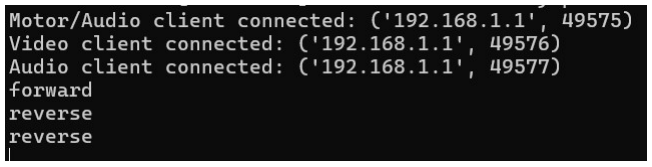
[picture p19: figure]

Figure 8.5: output from beagle board

40

# Chapter 9

# Scope for future applications

By incorporating future advancements, the relay pipe guided rover can become an even

more powerful tool for mine rescue operations, saving more lives and mitigating the

impact of disasters.

## 9.1 Technological Advancements

1. AI-Powered Autonomous Navigation: Develop advanced AI algorithms to

enable the rover to autonomously navigate through complex and changing

environments within the pipe. Utilize machine learning techniques to analyze

sensor data and adapt to unforeseen obstacles or pipe configurations.

2. Enhanced Sensor Capabilities: Incorporate more sophisticated sensors like

LiDAR or thermal cameras to provide detailed 3D mapping and detect heat

signatures of trapped miners. Integrate gas sensors with higher sensitivity and

specificity to detect a wider range of hazardous gases.

3. Improved Communication Systems: Explore higher-bandwidth optical fiber

technologies to transmit larger volumes of data, including high-resolution video

and real-time sensor readings. Develop robust error correction and redundancy

techniques to ensure reliable communication in challenging conditions.

4. Hybrid system: It enhances the rover’s reliability by integrating wired and

wireless communication for uninterrupted data transmission. Optical fiber pro-

41 vides high-speed, low-latency communication, while wireless fallback ensures

connectivity when fiber deployment is obstructed.

## 9.2 Application Expansion

1. Real-time Health Monitoring: Equip the rover with biometric sensors to monitor

the vital signs of trapped miners, such as heart rate, blood pressure, and oxygen

levels. Transmit this data to medical experts for real-time assessment and

guidance on medical interventions.

2. Structural Assessment: Utilize advanced imaging techniques and AI algorithms

to assess the structural integrity of the mine, identify potential hazards, and

inform rescue strategies.

3. Environmental Monitoring: Monitor environmental parameters like temperature,

humidity, and radiation levels to assess the impact of the disaster and guide

rescue efforts.

4. Remote Control and Tele operation: Develop intuitive user interfaces and

advanced tele operation techniques to enable remote operators to control the

rover with precision and efficiency.

## 9.3 Integration with Other Technology

1. Drone Integration: Collaborate with drones to provide aerial reconnaissance

and mapping of the disaster site, complementing the rover’s underground

capabilities.

2. IoT and Big Data: Connect the rover to the Internet of Things (IoT) to enable

remote monitoring, data analysis, and predictive maintenance. Utilize big data

analytics to identify patterns and trends in sensor data, improving decision-

making and resource allocation.

42

# Chapter 10

# Conclusion

This project focuses on developing a cutting-edge mine rescue rover designed specifi-

cally for post-collapse scenarios, where traditional communication and rescue methods

are ineffective. The rover is equipped with a robust wired communication system,

ensuring a stable, interference-free, and real-time data link between the rover and the

base station. This instantaneous transmission is critical in underground environments,

where wireless communication is unreliable due to physical obstructions and signal

loss. High-resolution imaging and environmental sensors are integral to the rover’s

functionality, allowing it to capture clear visuals and monitor hazardous conditions

such as toxic gases, temperature variations, and humidity levels. By combining

these features, the rover provides crucial real-time data to rescue teams, enabling

them to accurately assess the situation and respond effectively, even in confined and

challenging underground spaces.

Enhanced Rescue Capabilities: The rover is designed to navigate through a

strategically placed relay pipe, ensuring safe movement within collapsed or obstructed

passages. This pipe serves as a dedicated pathway, allowing the rover to reach

areas where miners may be trapped.A key innovation is its support for bidirectional

communication, enabling two-way audio and data transfer between rescue teams and

trapped individuals. This capability is essential for gathering first-hand information

from those inside the collapsed area and providing them with updates and support.

Additionally, the rover’s environmental monitoring system continuously measures gas

levels, temperature, and other parameters, offering a comprehensive real-time overview

43 of underground conditions. This continuous monitoring aids in formulating effective

rescue strategies, reducing risks, and adapting to changing conditions—significantly

improving the chances of a successful rescue mission.

Potential to Save Lives: By integrating state-of-the-art technology, this rover sets

a new benchmark in mine safety and rescue operations. Its wired communication

system ensures uninterrupted contact, overcoming one of the biggest challenges in

underground rescues—the loss of communication due to debris and structural obstruc-

tions. The rover’s high-quality imaging and real-time environmental monitoring bridge

the communication gap that often hampers traditional rescue methods. This constant

flow of data empowers rescue teams to make rapid, informed decisions, reducing

the time required to locate and assist trapped miners. Ultimately, the rover’s ability

to maintain real-time communication, monitor hazardous conditions, and navigate

through challenging environments is aimed at saving lives by accelerating response

times, improving situational awareness, and enhancing the overall effectiveness of

mine rescue operations.

44

# References

1. G. Junyao, G.Xueshan, Z. Wei, Z. Jianguo and W. Boyu, ”Coal Mine Detect

and Rescue Robot Design and Research”, 2008 IEEE International Conference

on Networking, Sensing and Control, Sanya, China, 2008, pp. 780-785, doi:

10.1109/ICNSC.2008.4525321

2. Hemanth Reddy A, Balla Kalyan, Ch. S. N. Murthy, ”Mine Rescue Robot

System A Review”, 2015 Global Challenges, Policy Framework Sustainable

Development for Mining of Mineral and Fossil Energy Resources (GCPF2015)

3. Yutan Li, MenggangLi, Hua Zhu, Eryi Hu, Chaoquan Tang,Peng Li,Shaoze

You,”Development and applications of rescue robots for explosion accidents in

coal mines”, J Field Robotics. 2019;1–24

4. S.g. Roh, D. W. Kim, J. -S. Lee, H. Moon and H. R. Choi, ”Modularized in-

pipe robot capable of selective navigation inside of pipelines”, 2008 IEEE/RSJ

International Conference on Intelligent Robots and Systems, Nice, France, 2008,

pp. 1724-1729, doi: 10.1109/IROS.2008.4650968

5. Ray, D. N., Das, R., Sebastian, B., Roy, B., & Majumder, S. (2016). Design and

Analysis Towards Successful Development of a Tele-Operated Mobile Robot

for Underground Coal Mines. In *CAD/CAM, Robotics and Factories of the

Future* (pp. 589–602). Springer, New Delhi.

6. BeagleBoard.org. (2024). BeagleY-AI — BeagleBoard Documentation. Re-

trieved from https://docs.beagleboard.org/boards/beagley/ai/index.

html.

45

7. Components101. (n.d.). MQ-135 Gas Sensor Pinout, Features, Alternatives,

Datasheet & Uses Guide. Retrieved from https://components101.com/

sensors/mq135-gas-sensor-for-air-quality

8. Ariff, M. F. M., Majid, Z., Setan, H., & Chong, A. K. (2010). Near-infrared

camera for night surveillance applications. Geoinformation Science Journal,

10(1), 38–48.

9. Kostenko, K. V. (2019). Real-time communication between robotic PLC and PC

via Ethernet-based protocols.

10. Eskafi, F., Ross, B., & Xiao, L. (2002). Internet Controlled Rover.
11. A. M. C. Rezende et al., ”Indoor Localization and Navigation Control Strategies

for a Mobile Robot Designed to Inspect Confined Environments,” 2020 IEEE

16th International Conference on Automation Science and Engineering (CASE),

Hong Kong, China, 2020, pp. 1427-1433, doi: 10.1109/CASE48305.2020.9217005.

12. Krishnamoorthy, S., & Kesava Panikkar, P. P. (2023). A comprehensive review

of different electric motors for electric vehicles application. International

Journal of Power Electronics and Drive Systems (IJPEDS), 15(1), 74-90.

Retrieved from

13. Kandasamy, N. K., Ramachandran, K. I., & Rajendran, P. (2022). A review of

Li-ion batteries for autonomous mobile robots: Perspectives and outlook for the

future. Journal of Power Sources, 541, 231766.

14. Kumar, L., & Jain, A. (2021). 3D printing – A review of processes, ma-

terials and applications in industry 4.0. Materials Today: Proceedings, 45,

2080-2086. Retrieved from https://www.sciencedirect.com/science/

article/pii/S2666412721000441

15. Wary, N., & Mandal, P. (2015). High-speed energy-efficient bi-directional

transceiver for on-chip global interconnects. IET Circuits, Devices & Systems,

9(5), 319-327.

46

16. Beniz, D. B., & Espindola, A. M. (2016). Using Tkinter of Python to

Create Graphical User Interface (GUI) for Scripts in LNLS. Proceedings of the

11th International Workshop on Personal Computers and Particle Accelerator

Controls, (pp. 1–4).

17. L. Zhou, Y. Dou, H. Liu, W. Zhang, J. Hu and C. Yang, ”Shared Control Method

for Coal Mine Rescue Robots,” 2021 5th CAA International Conference on

Vehicular Control and Intelligence (CVCI), Tianjin, China, 2021, pp. 1-6, doi:

10.1109/CVCI54083.2021.9661251.

18. R.R.Murphy, J. Kravitz, S. L. Stover and R. Shoureshi, ”Mobile robots in mine

rescue and recovery,” in IEEE Robotics Automation Magazine, vol. 16, no. 2,

pp. 91-103, June 2009, doi: 10.1109/MRA.2009.932521.

19. Yong Guo, Fuqiang Yang, Mining safety research in China: Understanding

safety research trends and future demands for sustainable mining industry,

Resources Policy, 10.1016/j.resourpol.2023.103632, 83, (103632), (2023).

20. A. Akbari, P. S. Chhabra, U. Bhandari and S. Bernardini, ”Intelligent Ex-

ploration and Autonomous Navigation in Confined Spaces,” 2020 IEEE/RSJ

International Conference on Intelligent Robots and Systems (IROS), Las Vegas,

NV, USA, 2020, pp. 2157-2164, doi: 10.1109/IROS45743.2020.9341525.

21. OpenAI. (2023). Introducing ChatGPT. Accessed: May 26, 2023. [Online].

Available: https://openai.com/blog/chatgpt

47

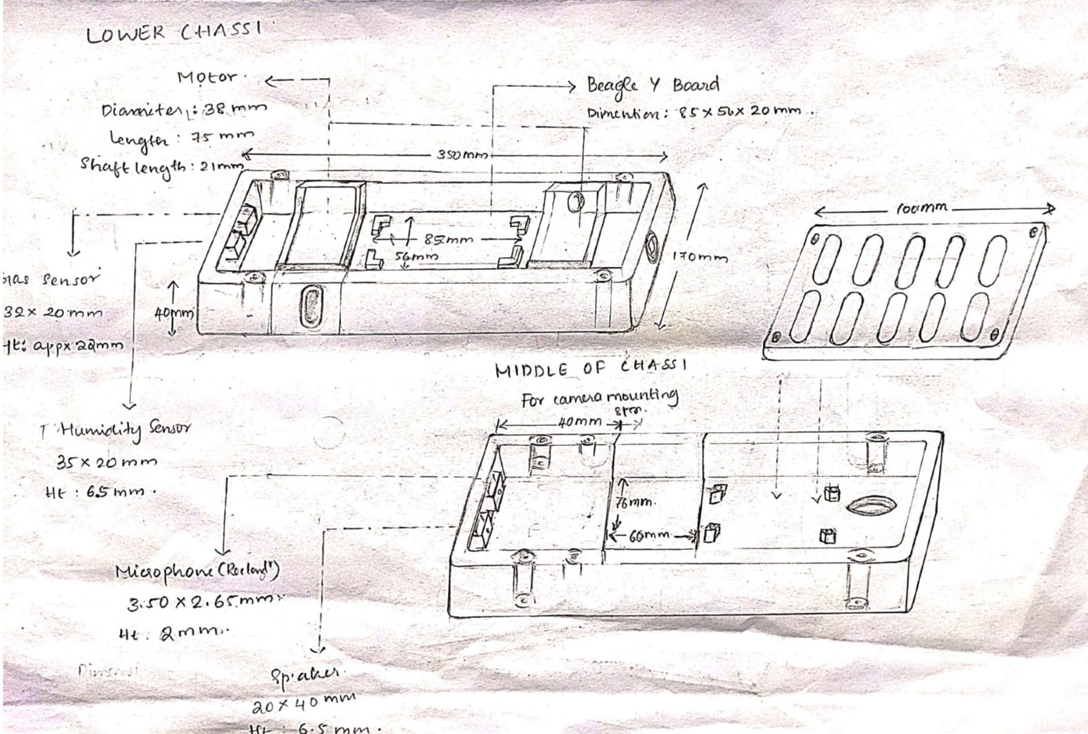
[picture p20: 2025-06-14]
Images/IMG-20250614-WA0019.jpg

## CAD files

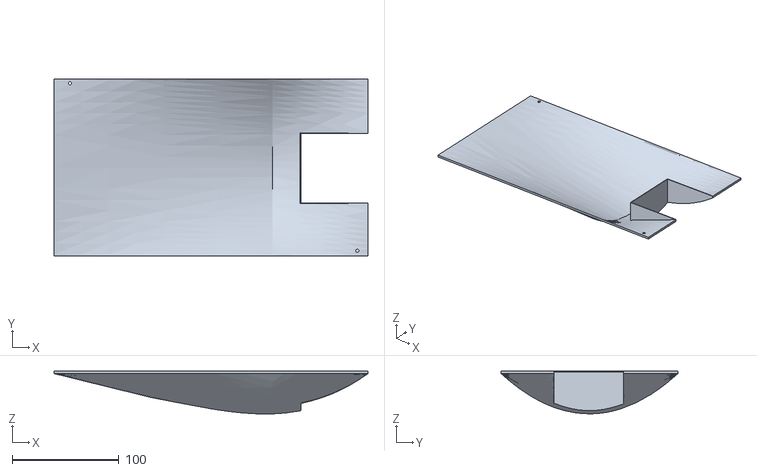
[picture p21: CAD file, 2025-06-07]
CAD Models/New top stl.STL
294.4 x 165.9 x 40.1

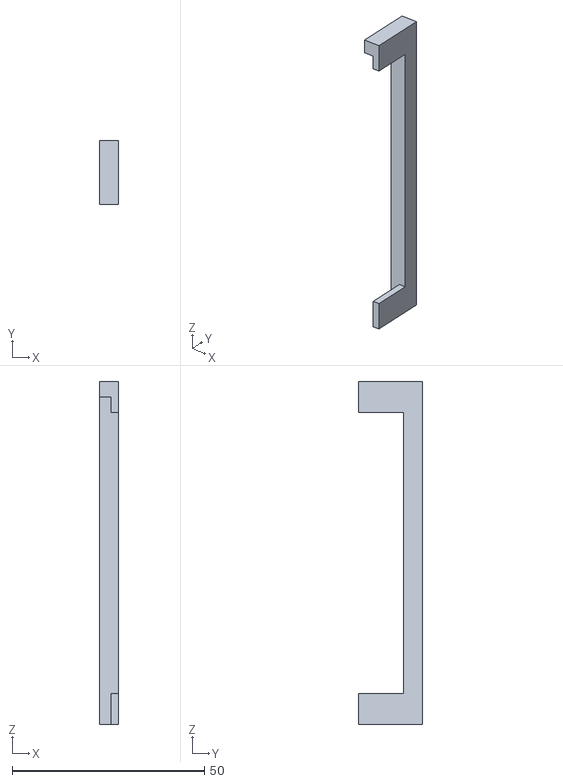
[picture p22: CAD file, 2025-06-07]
CAD Models/door upper.STL
5.00 x 16.6 x 89.2

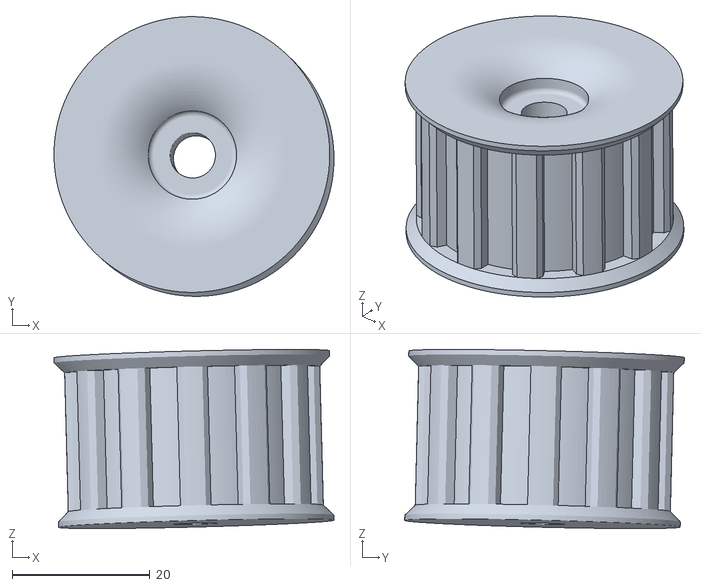
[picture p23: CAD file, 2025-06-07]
CAD Models/Assem1 - wheel new final-1.STL
40.6 x 40.6 x 26.0

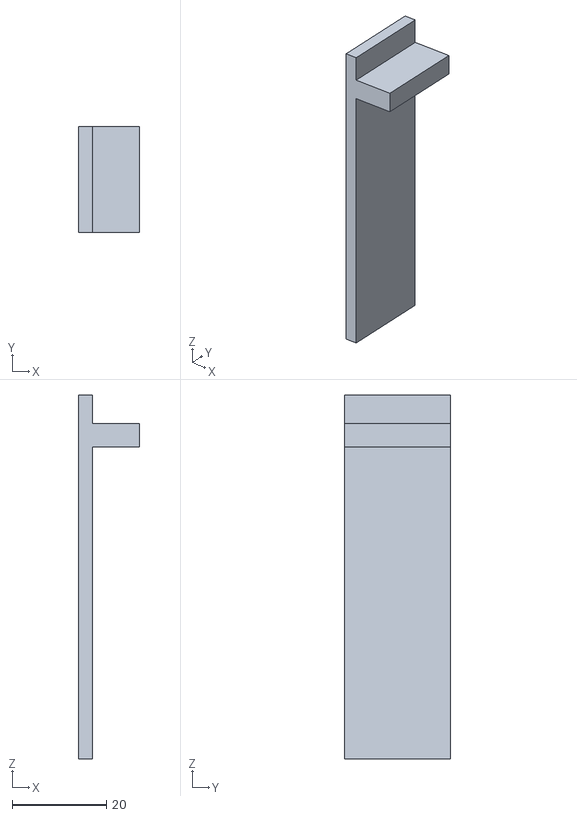
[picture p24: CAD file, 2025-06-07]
CAD Models/door slider.STL
13.0 x 22.5 x 77.2

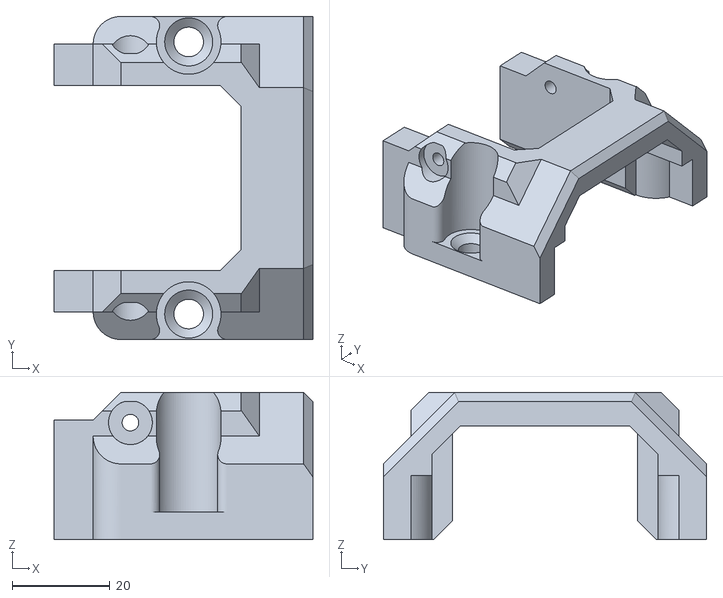
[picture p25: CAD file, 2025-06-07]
CAD Models/Camera_Support.STL
53.0 x 66.2 x 30.2

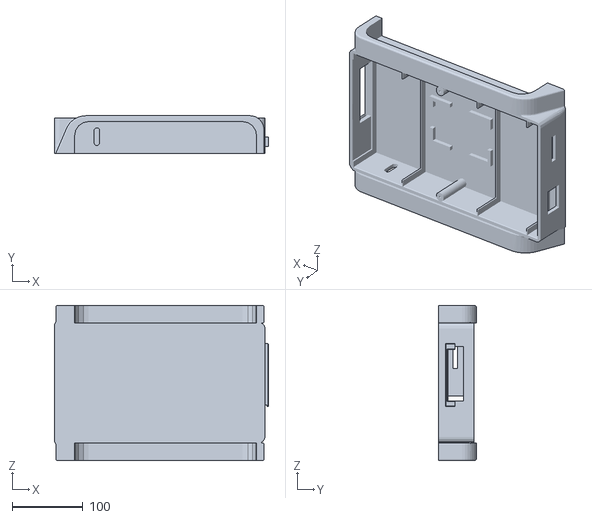
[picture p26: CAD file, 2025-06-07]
CAD Models/base new.STL
303.5 x 53.3 x 220.0

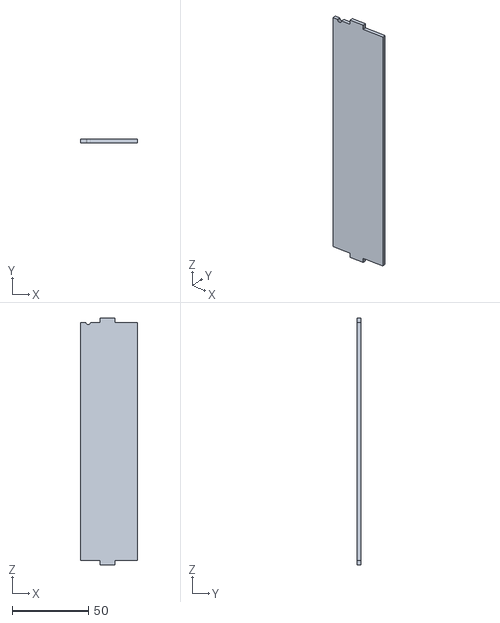
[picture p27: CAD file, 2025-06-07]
CAD Models/camera support holder.STL
37.4 x 2.31 x 161.6

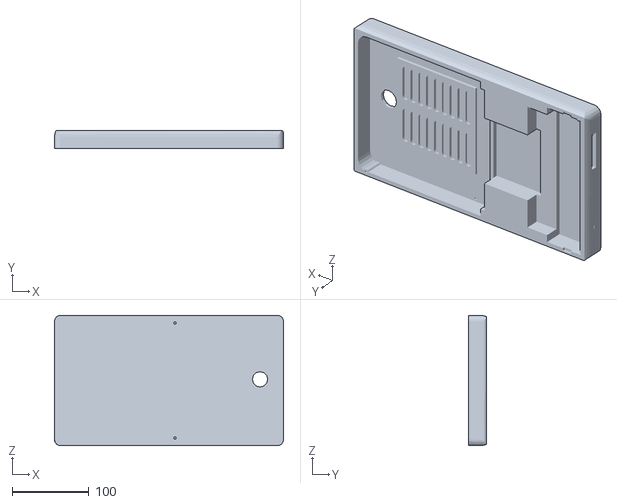
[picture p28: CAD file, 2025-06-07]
CAD Models/middle new.STL
298.5 x 24.0 x 170.0

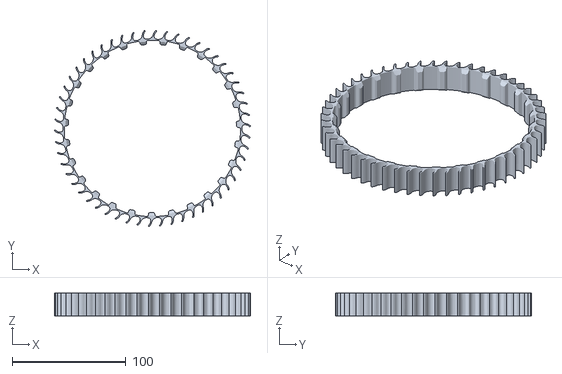
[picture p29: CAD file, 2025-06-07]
CAD Models/chain.STL
172.2 x 172.1 x 20.2

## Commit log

2025-06-07 Code for Base Station
    This code manages the base station functionality for the coal mine monitoring rover. It handles communication with the rover via RJ45 Ethernet, receives image and sensor data, and provides a control 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
2025-06-07 Create BeagleBoard.ipynb
    This code runs on the BeagleBoard AI and handles the rover’s onboard functionalities, including image processing, navigation control, and communication with the base station. It processes sensor inpu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
2025-06-07 CAD Models of Rover Parts
    This folder contains the 3D CAD models designed for the rover's mechanical structure, including the chassis, wheel system, camera mount, and internal component layout. The models were created using S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
    [Assem1 - wheel new final-1.STL, Camera_Support.STL, New top stl.STL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]
2025-06-07 BeagleBoard
    This code runs on the BeagleBoard and handles the rover’s onboard functionalities, including image processing, navigation control, and communication with the base station. It processes sensor inputs,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
2025-06-07 Beagle Board
    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
2025-06-07 Base Station
    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
2025-06-07 CAD Models
    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
    [Assem1 - wheel new final-1.STL, Camera_Support.STL, New top stl.STL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]
2025-06-07 Project Report
    The Project Report covers the design, development, and implementation of the coal mine monitoring rover, detailing the mechanical CAD modeling, RJ45 Ethernet communication system, and control archite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
2025-06-14 working.mp4
    Shows the working of prototype
